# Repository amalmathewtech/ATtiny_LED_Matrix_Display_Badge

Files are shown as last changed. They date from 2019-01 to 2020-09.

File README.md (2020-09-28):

# ATtiny_LED_Matrix_Display_Badge
An ATtiny85 based badge size PCB that can display alphabets and numbers .

Project Details: https://www.hackster.io/amalmathewtech/attiny-led-matrix-display-badge-f2c664


[url](https://twitter.com/Hacksterio/status/1091351536943415298)

[url](https://twitter.com/amalmathewtech/status/1158927944246366209)

[url](https://twitter.com/MicrochipMakes/status/1091068308395307015)

[url](https://twitter.com/MicrochipMakes/status/1305969818621882375)

Made With ❤ in OpenSource

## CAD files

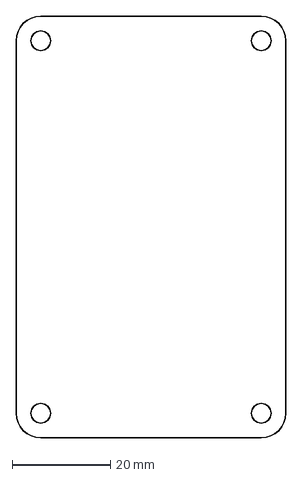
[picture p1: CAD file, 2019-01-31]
Edge Cut - DXF File/pcb badge.dxf
55.0 x 86.0 mm

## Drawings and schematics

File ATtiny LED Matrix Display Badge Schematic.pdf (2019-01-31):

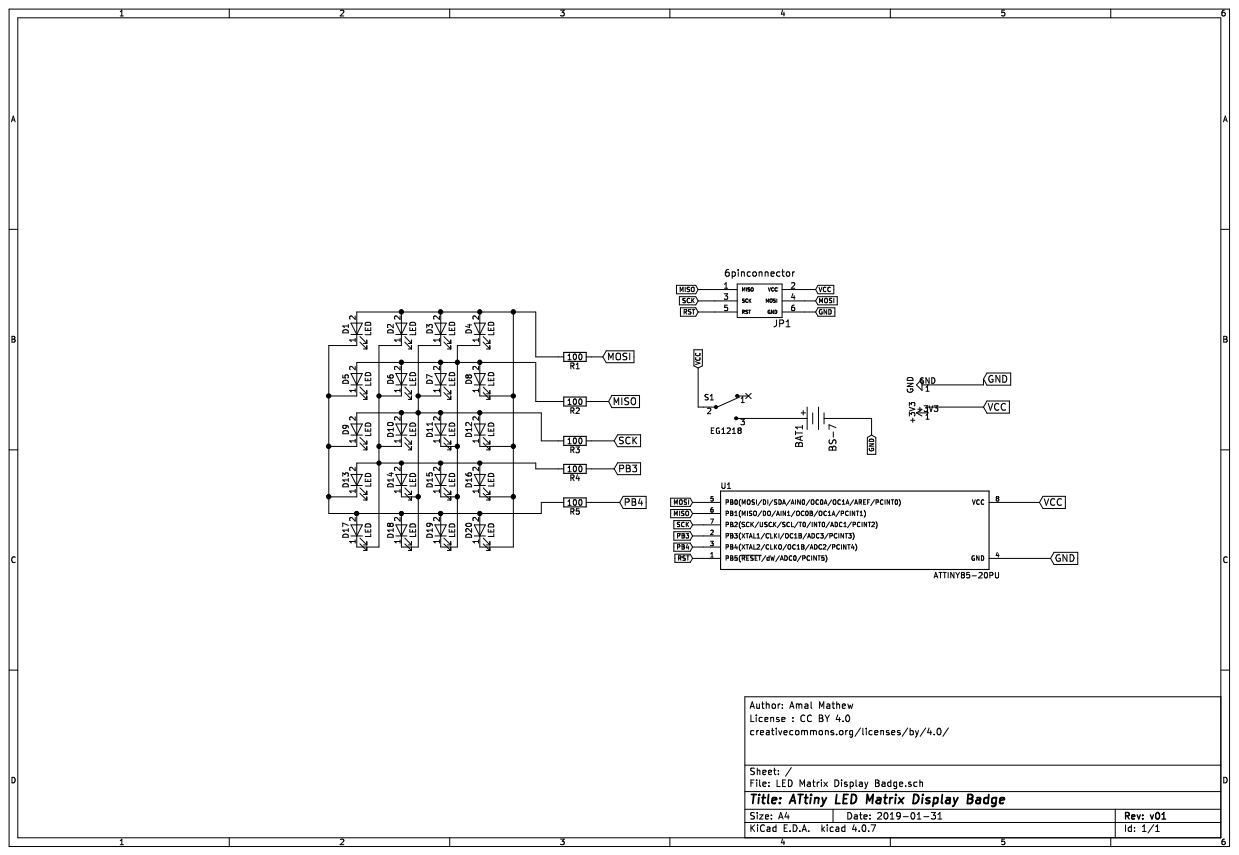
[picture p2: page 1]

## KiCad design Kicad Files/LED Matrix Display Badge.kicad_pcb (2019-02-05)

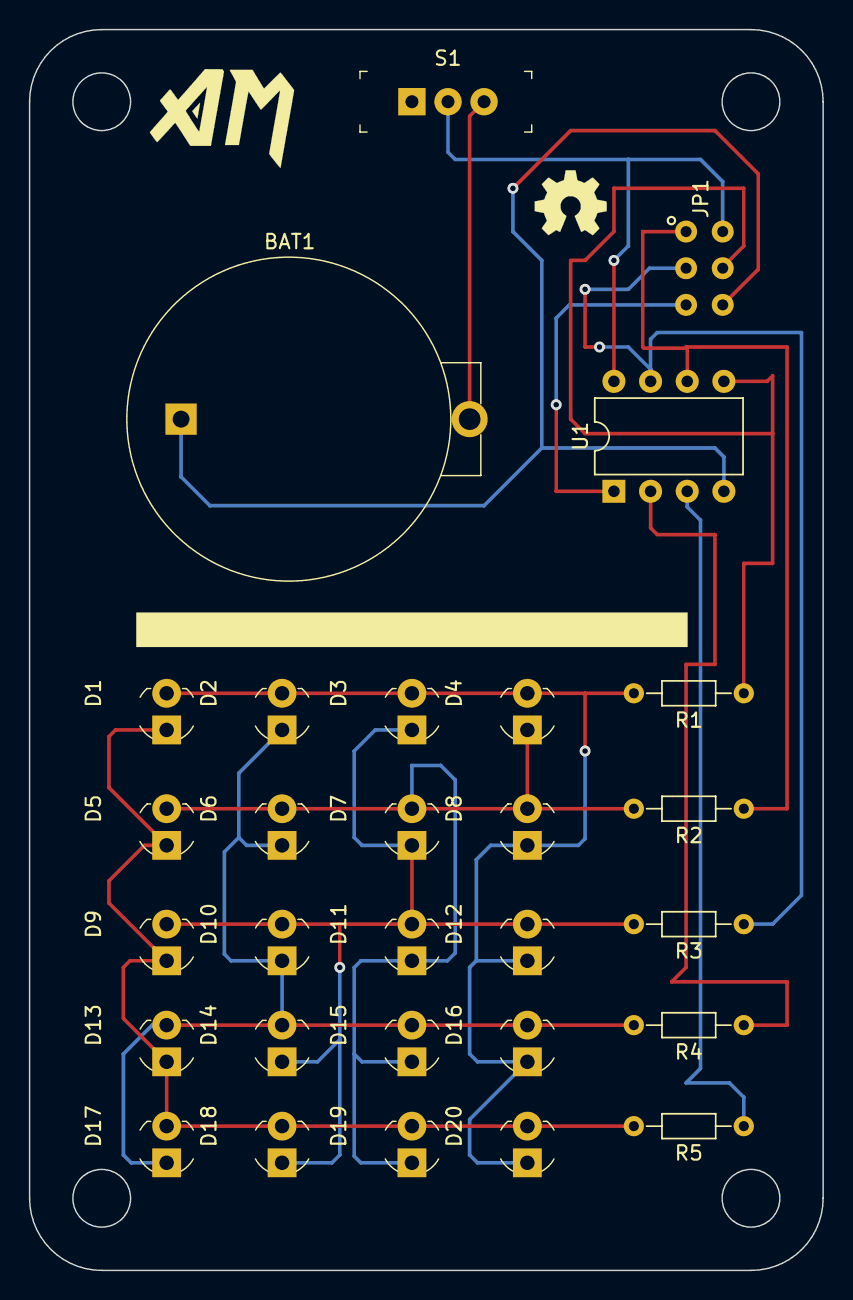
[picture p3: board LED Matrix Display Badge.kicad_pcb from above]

Board: 2 copper layers, 55.0 x 86.0 mm, 29 parts (0 on the bottom side), 14 nets.

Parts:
BAT1: BS-7; Battery_Holder_Coin_2032_BS-7
D1, D2, D3, D4, D5, D6, D7, D8, D9, D10, D11, D12, D13, D14, D15, D16, D17, D18, D19, D20: LED; LED_3mm_Radial
JP1: 6pinconnector; 6PINCONNECTOR
R1, R2, R3, R4, R5: 100; R_Axial_DIN0204_L3.6mm_D1.6mm_P7.62mm_Horizontal
S1: EG1218; Switch_Slide_11.6x4mm_EG1218
U1: ATTINY85-20PU; DIP-8_W7.62mm

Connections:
GND: BAT1.Neg, JP1.6, U1.4
MISO: JP1.1, R2.1, U1.6
MOSI: JP1.4, R1.1, U1.5
unnamed: BAT1.Pos, S1.3
unnamed: D1.1, D5.1, D9.1, D13.1, D17.2, D18.2, D19.2, D20.2, R5.2
unnamed: D1.2, D2.2, D3.2, D4.2, D8.1, D12.1, D16.1, D20.1, R1.2
unnamed: D2.1, D6.1, D10.1, D13.2, D14.2, D15.2, D16.2, D17.1, R4.2
unnamed: D3.1, D7.1, D9.2, D10.2, D11.2, D12.2, D14.1, D18.1, R3.2
unnamed: D4.1, D5.2, D6.2, D7.2, D8.2, D11.1, D15.1, D19.1, R2.2
PB3: R4.1, U1.2
PB4: R5.1, U1.3
RST: JP1.5, U1.1
SCK: JP1.3, R3.1, U1.7
VCC: JP1.2, S1.2, U1.8

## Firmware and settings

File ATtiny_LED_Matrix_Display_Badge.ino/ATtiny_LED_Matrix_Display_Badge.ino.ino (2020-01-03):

#define MAP_START      32

#define DISPLAY_WIDTH  4
#define DISPLAY_HEIGHT 5

// "pixels" per second
#define SPEED          12       

// the text to display
#define DISPLAY_STRING "  ATTINY LED MATRIX DISPLAY BADGE    "





// maps characters to their 4x5 grid 
unsigned long characterMap[59];

// set up a character in the characterMap
void Chr(char theChar, unsigned long value) {
  characterMap[theChar - MAP_START] = value;
}

// The offset of our string in the display
int offset = 0;
unsigned long lastMillis = 0;
unsigned long currentMillis = 0;
unsigned int timeout;

char myString[] = DISPLAY_STRING;
int length = sizeof(myString);

// render the string on the given offset
void renderString(char *theString, int offset) {
  int index = 0;
  while (theString[index]) {
    renderCharacter(theString[index], offset - index * (DISPLAY_WIDTH + 1));
    index++;
  }
}

// render a character on the given offset
void renderCharacter(char theChar, int charOffset) {
  if (charOffset <= -DISPLAY_WIDTH || charOffset > DISPLAY_WIDTH) {
    // off the 'screen' nothing to do
    return;
  }

  unsigned long graphic = characterMap[theChar - MAP_START];

  for (byte y = 0; y < DISPLAY_HEIGHT; y++) {
    for (byte x = 0; x < DISPLAY_WIDTH; x++) {
      
      setPixel(3 - x + charOffset, y, graphic & 0x1);
      graphic = graphic >> 1;
    }
  }
}

// light a pixel at the given coordinates
void setPixel(byte x, byte y, boolean ledStatus) {
  if (x >= 0 && x < DISPLAY_WIDTH) {
    if (y <= x) {
      x++;
    }
    setLed(y, x, ledStatus);
  }
}

// turn on the pins to light a LED
void setLed(byte vin, byte gnd, boolean ledStatus) {
  delayMicroseconds(500);
  pinMode(0, INPUT); 
  pinMode(1, INPUT); 
  pinMode(2, INPUT); 
  pinMode(3, INPUT); 
  pinMode(4, INPUT); 

  if(!ledStatus) return;

  pinMode(vin, OUTPUT);   
  pinMode(gnd, OUTPUT); 
  digitalWrite(vin, HIGH);
  digitalWrite(gnd, LOW); 
}

// runs at start
void setup() {
  // set up render map

  // Rows:   1---2---3---4---5---
  Chr('A', 0b10011001111110010110);
  Chr('B', 0b01111001011110010111);
  Chr('C', 0b11100001000100011110);
  Chr('D', 0b01111001100110010111);
  Chr('E', 0b11110001011100011111);
  Chr('F', 0b00010001011100011111);
  Chr('G', 0b01101001110100011110);
  Chr('H', 0b10011001111110011001);
  Chr('I', 0b11100100010001001110);
  Chr('J', 0b00100101010001001110);
  Chr('K', 0b10010101001101011001);
  Chr('L', 0b11110001000100010001);
  Chr('M', 0b10011001111111111001);
  Chr('N', 0b10011001110110111001);
  Chr('O', 0b01101001100110010110);
  Chr('P', 0b00010001011110010111);
  Chr('Q', 0b10000110110110010110);
  Chr('R', 0b10010101011110010111);
  Chr('S', 0b11111000111100011111);
  Chr('T', 0b01000100010001001110);
  Chr('U', 0b01101001100110011001);
  Chr('V', 0b00100101100110011001);
  Chr('W', 0b01101111111110011001);
  Chr('X', 0b10011001011010011001);
  Chr('Y', 0b00110100011010011001);
  Chr('Z', 0b11110010010010001111);
  Chr(' ', 0b00000000000000000000);
  Chr('1', 0b11100100010001100100);
  Chr('2', 0b11110001011010000111);
  Chr('3', 0b01111000011010000111);
  Chr('4', 0b01001111010101100100);
  Chr('5', 0b01111000011100011111);
  Chr('6', 0b01101001011100010110);
  Chr('7', 0b00010010010010001111);
  Chr('8', 0b01101001011010010110);
  Chr('9', 0b01101000111010010110);
  Chr('0', 0b01101001110110110110);

  // how long to wait between shifting the display
  timeout = 1000 / SPEED;
}

// loops continuously
void loop() {
  currentMillis = millis();

  renderString(myString, offset);

  if (currentMillis - lastMillis > timeout) {
    lastMillis = currentMillis;
    // shift string over one "pixel"
    offset++;
    // if it's past the length of the string, start over from the beginning
    if (offset > length * (DISPLAY_WIDTH + 1)) {
      offset = -DISPLAY_WIDTH;
    }
  }
}

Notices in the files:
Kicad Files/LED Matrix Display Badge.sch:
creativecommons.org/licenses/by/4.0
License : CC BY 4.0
